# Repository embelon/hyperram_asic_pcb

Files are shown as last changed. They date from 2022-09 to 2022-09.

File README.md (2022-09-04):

# hyperram_asic_pcb
Test PCB for CARAVEL ASIC manufactured by efables.com in Open Source Shuttles to check HyperRAM memory controller IP connected to RISC-V through Wishbone bus.

HyperRAM controller was submitted in MPW-2 as part of multi project: 
https://platform.efabless.com/projects/66
and in MPW-3 on its own (with additional 1kB of OpenRAM):
https://platform.efabless.com/projects/501

HyperRAM controller IP was created to work with Cypress S27KL0641:
https://github.com/embelon/wb_hyperram

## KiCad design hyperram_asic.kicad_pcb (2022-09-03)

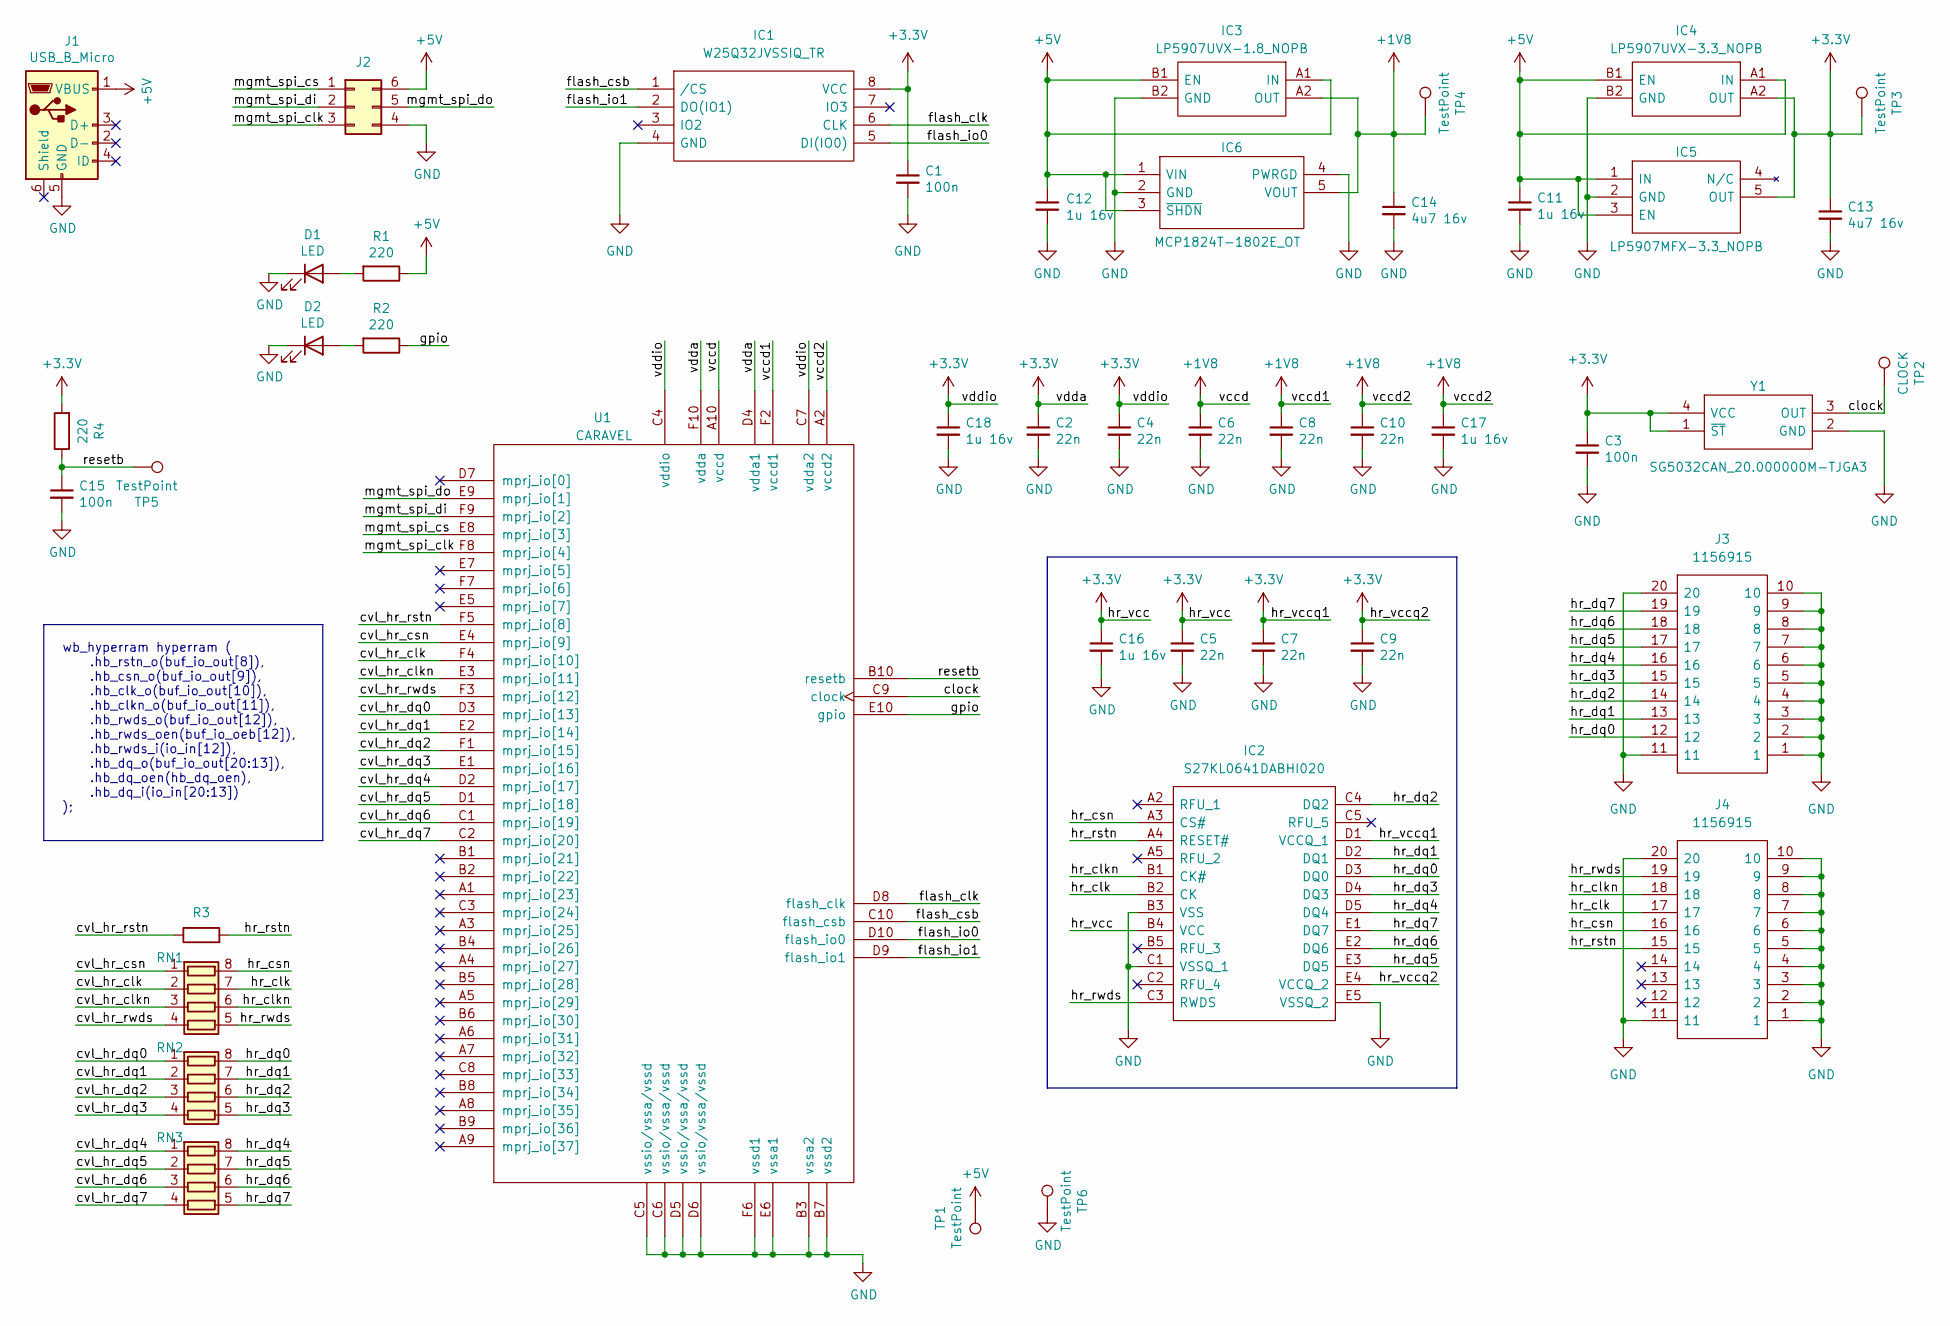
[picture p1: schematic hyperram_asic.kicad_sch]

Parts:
C1, C3, C15: 100n; C_0402_1005Metric_Pad0.74x0.62mm_HandSolder; Part CGA3E2X7R1H223K080AA
C2, C4, C5, C6, C7, C8, C9, C10: 22n; C_0402_1005Metric_Pad0.74x0.62mm_HandSolder; Part CGA3E2X7R1H223K080AA
C11, C12, C16, C17, C18: 1u 16v; C_0805_2012Metric_Pad1.18x1.45mm_HandSolder; Part CL10A105KO8NNNC
C13, C14: 4u7 16v; C_0805_2012Metric_Pad1.18x1.45mm_HandSolder; Part CC0603KRX5R7BB475
D1, D2: LED; LED_0805_2012Metric_Pad1.15x1.40mm_HandSolder; Part LS Q976-NR-1
IC1: W25Q32JVSSIQ_TR; SOIC127P790X216-8N; Mouser Part Number 454-W25Q32JVSSIQTR
IC2: S27KL0641DABHI020; BGA24C100P5X5_600X800X100; Manufacturer_Part_Number S27KL0641DABHI020; Mouser Part Number 727-S27KL0641DABHI02
IC3: LP5907UVX-1.8_NOPB; BGA4C35P2X2_64X64X44; Mouser Part Number 926-LP5907UVX1.8NOPB
IC4: LP5907UVX-3.3_NOPB; BGA4C35P2X2_64X64X33; Mouser Part Number 926-LP5907UVX3.3NOPB
IC5: LP5907MFX-3.3_NOPB; SOT95P280X145-5N; Mouser Part Number 595-LP5907MFX-3.3NPB
IC6: MCP1824T-1802E_OT; SOT95P270X145-5N; Mouser Part Number 579-MCP1824T-1802EOT
J1: USB_B_Micro; UJ2MIBHGSMTTR; Part 105017-0001
J2: Conn_02x03_Counter_Clockwise; PinHeader_2x03_P2.54mm_Vertical
J3, J4: 1156915; Mouser Part Number 651-1156915
R1, R2, R4: 220; R_0603_1608Metric; Part ‎RC0603JR-07100RL‎
R3: R; R_0603_1608Metric
RN1, RN2, RN3: CAY16-22R0F4LF; CAY16000J4LF
TP1, TP3, TP4, TP5, TP6: TestPoint; TestPoint_Pad_D1.0mm
TP2: CLOCK; TestPoint_Pad_D1.0mm
U1: CARAVEL; WLCSP-60_P0.5mm
Y1: SG5032CAN_20.000000M-TJGA3; SG5032CAN20000000MTJGA3; Mouser Part Number 732-5032CAN20.0TJGA3

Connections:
+1V8: C6.1, C8.1, C10.1, C14.1, C17.1, IC3.A2 (OUT), IC6.5 (VOUT), TP4.1, U1.A2 (vccd2), U1.A10 (vccd), U1.F2 (vccd1)
+3V3: C1.1, C2.1, C3.1, C4.1, C5.1, C7.1, C9.1, C13.1, C16.1, C18.1, IC1.8 (VCC), IC2.B4 (VCC), IC2.D1 (VCCQ_1), IC2.E4 (VCCQ_2), IC4.A2 (OUT), IC5.5 (OUT), R4.2, TP3.1, U1.C4 (vddio), U1.C7 (vdda2), U1.D4 (vdda1), U1.F10 (vdda), Y1.1 (~ST), Y1.4 (VCC)
+5V: C11.1, C12.1, IC3.A1 (IN), IC3.B1 (EN), IC4.A1 (IN), IC4.B1 (EN), IC5.1 (IN), IC5.3 (EN), IC6.1 (VIN), IC6.3 (~SHDN), J1.1 (VBUS), J2.6, R1.1, TP1.1
/clock: TP2.1, U1.C9 (clock), Y1.3 (OUT)
/cvl_hr_clk: RN1.2 (R2.1), U1.F4 (mprj_io[10])
/cvl_hr_clkn: RN1.3 (R3.1), U1.E3 (mprj_io[11])
/cvl_hr_csn: RN1.1 (R1.1), U1.E4 (mprj_io[9])
/cvl_hr_dq0: RN2.1 (R1.1), U1.D3 (mprj_io[13])
/cvl_hr_dq1: RN2.2 (R2.1), U1.E2 (mprj_io[14])
/cvl_hr_dq2: RN2.3 (R3.1), U1.F1 (mprj_io[15])
/cvl_hr_dq3: RN2.4 (R4.1), U1.E1 (mprj_io[16])
/cvl_hr_dq4: RN3.1 (R1.1), U1.D2 (mprj_io[17])
/cvl_hr_dq5: RN3.2 (R2.1), U1.D1 (mprj_io[18])
/cvl_hr_dq6: RN3.3 (R3.1), U1.C1 (mprj_io[19])
/cvl_hr_dq7: RN3.4 (R4.1), U1.C2 (mprj_io[20])
/cvl_hr_rstn: R3.1, U1.F5 (mprj_io[8])
/cvl_hr_rwds: RN1.4 (R4.1), U1.F3 (mprj_io[12])
/flash_clk: IC1.6 (CLK), U1.D8 (flash_clk)
/flash_csb: IC1.1 (/CS), U1.C10 (flash_csb)
/flash_io0: IC1.5 (DI(IO0)), U1.D10 (flash_io0)
/flash_io1: IC1.2 (DO(IO1)), U1.D9 (flash_io1)
/gpio: R2.1, U1.E10 (gpio)
/hr_clk: IC2.B2 (CK), J4.17, RN1.7 (R2.2)
/hr_clkn: IC2.B1 (CK#), J4.18, RN1.6 (R3.2)
/hr_csn: IC2.A3 (CS#), J4.16, RN1.8 (R1.2)
/hr_dq0: IC2.D3 (DQ0), J3.12, RN2.8 (R1.2)
/hr_dq1: IC2.D2 (DQ1), J3.13, RN2.7 (R2.2)
/hr_dq2: IC2.C4 (DQ2), J3.14, RN2.6 (R3.2)
/hr_dq3: IC2.D4 (DQ3), J3.15, RN2.5 (R4.2)
/hr_dq4: IC2.D5 (DQ4), J3.16, RN3.8 (R1.2)
/hr_dq5: IC2.E3 (DQ5), J3.17, RN3.7 (R2.2)
/hr_dq6: IC2.E2 (DQ6), J3.18, RN3.6 (R3.2)
/hr_dq7: IC2.E1 (DQ7), J3.19, RN3.5 (R4.2)
/hr_rstn: IC2.A4 (RESET#), J4.15, R3.2
/hr_rwds: IC2.C3 (RWDS), J4.19, RN1.5 (R4.2)
/mgmt_spi_clk: J2.3, U1.F8 (mprj_io[4])
/mgmt_spi_cs: J2.1, U1.E8 (mprj_io[3])
/mgmt_spi_di: J2.2, U1.F9 (mprj_io[2])
/mgmt_spi_do: J2.5, U1.E9 (mprj_io[1])
/resetb: C15.1, R4.1, TP5.1, U1.B10 (resetb)
GND: C1.2, C2.2, C3.2, C4.2, C5.2, C6.2, C7.2, C8.2, C9.2, C10.2, C11.2, C12.2, C13.2, C14.2, C15.2, C16.2, C17.2, C18.2, D1.1 (K), D2.1 (K), IC1.4 (GND), IC2.B3 (VSS), IC2.C1 (VSSQ_1), IC2.E5 (VSSQ_2), IC3.B2 (GND), IC4.B2 (GND), IC5.2 (GND), IC6.2 (GND), IC6.4 (PWRGD), J1.5 (GND), J2.4, J3.1, J3.2, J3.3, J3.4, J3.5, J3.6, J3.7, J3.8, J3.9, J3.10, J3.11, J3.20, J4.1, J4.2, J4.3, J4.4, J4.5, J4.6, J4.7, J4.8, J4.9, J4.10, J4.11, J4.20, TP6.1, U1.B3 (vssa2), U1.B7 (vssd2), U1.C5 (vssio/vssa/vssd), U1.C6 (vssio/vssa/vssd), U1.D5 (vssio/vssa/vssd), U1.D6 (vssio/vssa/vssd), U1.E6 (vssa1), U1.F6 (vssd1), Y1.2 (GND)
unnamed: D1.2 (A), R1.2
unnamed: D2.2 (A), R2.2

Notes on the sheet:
wb_hyperram hyperram ( .hb_rstn_o(buf_io_out[8]), .hb_csn_o(buf_io_out[9]), .hb_clk_o(buf_io_out[10]), .hb_clkn_o(buf_io_out[11]), .hb_rwds_o(buf_io_out[12]), .hb_rwds_oen(buf_io_oeb[12]), .hb_rwds_i(io_in[12]), .hb_dq_o(buf_io_out[20:13]), .hb_dq_oen(hb_dq_oen), .hb_dq_i(io_in[20:13]) );

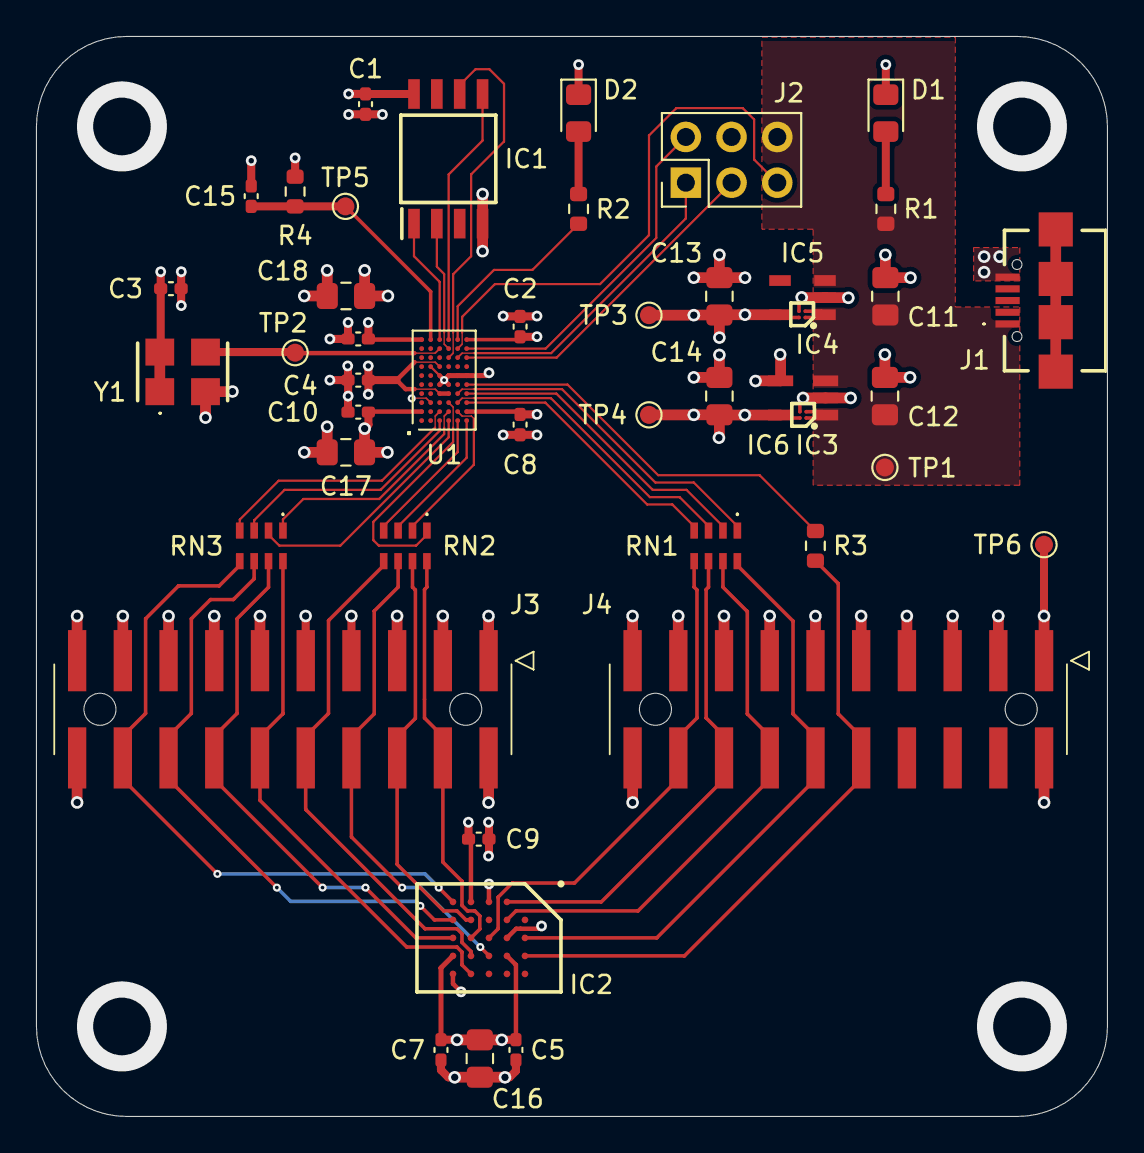
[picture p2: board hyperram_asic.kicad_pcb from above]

Board: 4 copper layers, 59.5 x 60.0 mm, 45 parts (0 on the bottom side), 43 nets.
